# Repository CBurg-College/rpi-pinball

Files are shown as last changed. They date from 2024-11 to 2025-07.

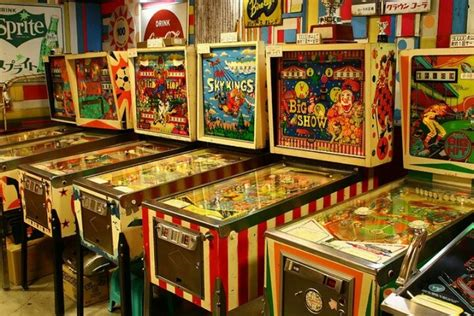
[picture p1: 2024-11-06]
installatie/testen/achtergrond.png

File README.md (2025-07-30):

## Deze repository

#### Introductie

De repositories **pxt-pinball** en **rpi-pinball** vormen een twee-eenheid.
Repository **pxt-pinball** is een uitbreiding voor **MakeCode** om de **micro:bit** te programmeren.
Het programma op de **micro:bit** werkt samen met het host-programma **Pinball** op de **Raspberry Pi**.
Repository **rpi-pinball** (deze repository dus) bevat de benodigde software en code hiervoor.
Het programma op de **micro:bit** stuurt de flipperkast dus aan via het programma **Pinball**.

#### De submappen

Submap **broncode** bevat het code-project waarmee het programma Flipperkast wordt gebouwd.
Deze is alleen interessant als het programma moet worden gewijzigd.

Submap **hardware** beschrijft de elektronische componenten in de flipperkast en hoe deze aan te sluiten.
Het bevat ook de bestanden om nieuwe flippers met de lasersnijder te snijden en deze zo nodig aan te passen.

Submap **installatie** biedt de mogelijkheid om de de **SD-kaart** van de Raspberry Pi opnieuw te installeren.
In deze map bevinden zich ook de bestanden om de flipperkast te testen.

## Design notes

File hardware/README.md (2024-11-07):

## Hardware herstellen

Een beschrijving van de flipperkast vind je in:
* **Flipperkast Werktekeningen.pdf**

Dit bestand geëxporteerd uit:
* **Flipperkast Werktekeningen.docx**

Om de elektronica van de flipperkast te herstellen, moet je kunnen solderen.
De informatie over aansluitingen en de te gebruiken onderdelen vind je in:
* **pin-aansluiting.md**
* **onderdelen.md**

Voor het vervangen van de flippers vind je de informatie in de map **flippers**.

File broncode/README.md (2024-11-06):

## Het programma Flipperkast

#### IDE Geany

Het programma **Flipperkast** is als een **Geany-project** gebouwd.
Op de Raspberry is de IDE **Geany** standaard geïnstalleerd.
Het project **Flipperkast.geany** kan daarmee worden geopend.
In de map **Flipperkast** staat de broncode.
Er is maar één code-bestand in het project aanwezig: **Flipperkast.cpp**.
Dit bestand bevat alle code van het programma.

#### C++

De code-taal van het programma **Flipperkast** is C++.
Het programma maakt gebruikt van de classes "Video" en "RgbLed" uit de code-bibliotheek **DeviceLib**.
Deze bibliotheek is als het goed is geïnstalleerd (zie bij **installatie/blanco**).
De programma-code moet samen werken met de MakeCode-uitbreiding **Flipperkast**.
De code hiervan vind je in het bestand **main.ts** van de repository **pxt-flipperkast**.

#### CLASS VIDEO

De class **Video** biedt de volgende instructies:

**Afspeelvenster**
* setTitle("Titel van het afspeelvenster");
* setSize(breedte,hoogte);
* setFullscreen();

**Frame na frame afspelen**
* start("Bestandsnaam van een video");
* play()
* rewind()
* stop()

De instructie **play** vertoont steeds het volgende frame.

**Hele video afspelen**
* play("Pad naar en bestandsnaam van een video");

**Afbeelding tonen**
* show("Pad naar en bestandsnaam van een afbeelding");

#### CLASS RGBLED

De class **RgbLed** biedt de volgende instructies:

**Instelling**
* setPin(rood,groen,blauw);
* setConnection(VCC of GND);

**Kleur**
* setColor(RED of GREEN of BLUE of YELLOW of MAGENTA of CYAN of WHITE);
* setColor(rood,groen,blauw);

**Aan/uit**
* on();
* off();

In de code mogen de instructies **setPin** en **setConnection** niet worden gewijzigd vanwege de hardware.

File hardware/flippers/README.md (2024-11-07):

## De flippers van de flipperkast

#### Het ontwerp

Het ontwerp staat in twee bestanden:
* **flipper.skp**
* **flipper.svg**

Eventuele wijzigingen kunnen in SketchUp worden gemaakt (flipper.skp),
maar de software bij de lasersnijder (**LightBurn**) heeft een svg-bestand nodig (flipper.svg).
Om in SketchUp het ontwerp als svg-bestand (flipper.svg) te exporteren is een **extension** nodig.

#### SketchUp

Het bestand **flipper.skp** is gemaakt met SketchUp Make versie 2017.
Dit is de laatste vrij installeerbare versie, omdat er nu een online versie bestaat.
Maar helaas, daarmee kun je je ontwerp niet voor de lasersnijder exporteren.
Vandaar dat we zijn aangewezen op de versie van 2017.
In de map **SVG-extension** vind je de plugin waarmee je een svg-bestand kunt exporteren:
**sketchup-svg-outline-plugin-v1.2.rbz**.
Installeer de plugin via de **Extension manager** van SketchUp (in het **Window**-menu).
**SketchUp Make 2017** kun je downloaden van https://www.filehorse.com/download-sketchup-make-64/

#### LightBurn

Het programma *LightBurn* is met licentie voor één gebruiker op de laptop van D&P geïnstalleerd.
De lasersnijder moet op de USB-ingang met het pijltje worden aangesloten.

Het bestand **flipper.svg** wordt in **LightBurn** geïmporteerd.
In deze map vind je twee bestanden waarin dat al is gebeurd:
* **flipper.lbrn2**
* **flipper20x.lbrn2**

Het bestand *flipper20x.lbrn* bevat 20 stuks flippers die uit een plaat van 55x35 cm wordt gesneden.
Gebruik een plaat triplex (4 mm dik) om de flippers uit te snijden.

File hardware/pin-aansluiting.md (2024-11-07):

#### Op de Raspberry zijn de pinnen als volgt aangesloten:

**pin  2**  ingang   **sensor poort 1**

**pin  3**  ingang   **sensor poort 2**

**pin 27**  uitgang  **rgb led 1**, kleurwaarde rood

**pin 17**  uitgang  **rgb led 1**, kleurwaarde groen

**pin 22**  uitgang  **rgb led 1**, kleurwaarde blauw

**pin 20**  uitgang  **rgb led 2**, kleurwaarde rood

**pin 16**  uitgang  **rgb led 2**, kleurwaarde groen

**pin 21**  uitgang  **rgb led 2**, kleurwaarde blauw

**pin 19**  uitgang  **rgb led 3**, kleurwaarde rood

**pin 13**  uitgang  **rgb led 3**, kleurwaarde groen

**pin 26**  uitgang  **rgb led 3**, kleurwaarde blauw

**pin  7**  ingang   **micro:bit P0**, handshaking: data valid

**pin  8**  uitgang  **micro:bit P3**, handshaking: data received

**pin  6**  uitgang  **micro:bit P1**, poort 1 bezet

**pin  5**  uitgang  **micro:bit P2**, poort 2 bezet

**pin 18**  ingang   **micro:bit P20**, media select

**pin 23**  ingang   **micro:bit P19**, media select

**pin 24**  ingang   **micro:bit P13**, led select

**pin 25**  ingang   **micro:bit P12**, led select

**pin 11**  ingang   **micro:bit P14**, led kleur: roodwaarde

**pin  9**  ingang   **micro:bit P15**, led kleur: groenwaarde

**pin 10**  ingang   **micro:bit P16**, led kleur: blauwwaarde

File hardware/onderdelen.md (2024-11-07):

#### Op de Raspberry zijn de volgende onderdelen aangesloten:

**RGB-led**:         mat, 10 mm doorsnede, common-VCC (te verkrijgen bij diverse leveranciers)

**Weerstand**:       330 Ohm (te verkrijgen bij diverse leveranciers)

**Laser poort**:     650 nm laser (rood), 5V (te verkrijgen bij TinyTronics, SKU000135)

**Sensor poort**:    sensor voor rood licht, 5V (te verkrijgen bij TinyTronics, SKU001061)

**Edge connector**:  Tru Components uitbreidingsmodule micro:bit (te verkrijgen bij Conrad, 2268132-83)

**Power converter**: TracoPower TSR 1-2433 (te verkrijgen bij Conrad, 156671-83)

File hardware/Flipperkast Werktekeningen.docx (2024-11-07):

# FLIPPERKAST Werktekening (blad 1)

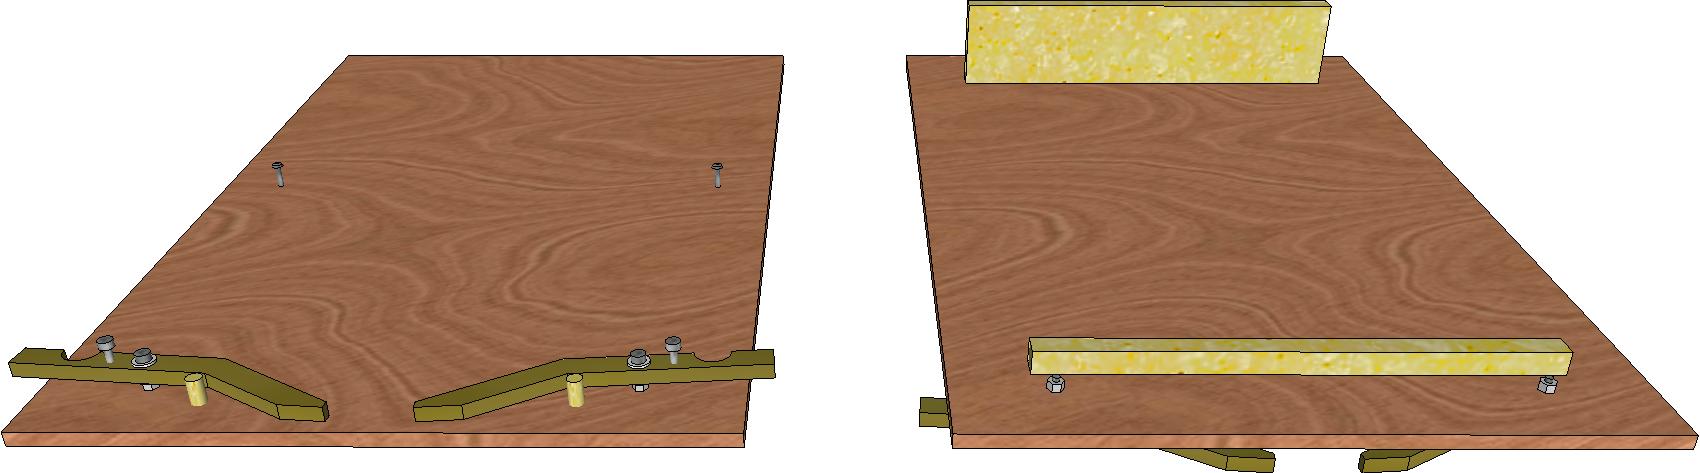
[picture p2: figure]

2

3

6

4

BOVENKANT

ONDERKANT

4

BOVENAANZICHT

ONDERAANZICHT

5

1

VOORAANZICHT

7

9

8

4

1

6

# FLIPPERKAST Werktekening (blad 2)

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
ONDERAANZICHT

# FLIPPERKAST Werktekening (blad 3)

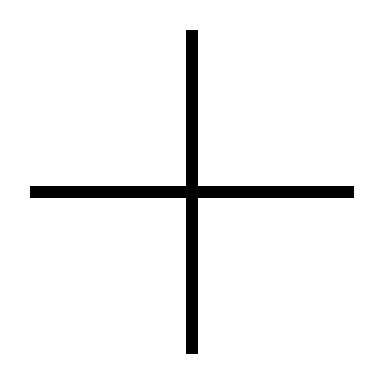
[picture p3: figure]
Toevoegen silhouet

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
BOVENAANZICHT

BOVENAANZICHT

Ø6

Ø4

Ø6

Ø4

1

# FLIPPERKAST Werktekening (blad 4)

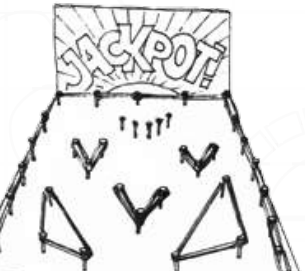
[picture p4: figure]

Ø3

ZIJAANZICHT

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
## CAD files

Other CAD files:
hardware/flippers/flippers.skp

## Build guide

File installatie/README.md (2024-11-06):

## Installatie van de Raspberry Pi

Onder de flipperkast zit een Raspberry Pi die de programma-instructies verwerkt.
De programma-instructies krijgt dit computertje van een micro:bit.

Een Raspberry doet niets zonder een SD-kaart met de benodige software.
Installeer de software volgens de onderstaande procedure.

Om te weten of de flipperkast correct functioneert, ga je naar de map **testen**.

## Procedure

#### 1. Raspberry Pi Imager

Gebruik de **Raspberry Pi Imager** tool om het standaard **Raspberry Pi OS** op een SD-kaart te schrijven.
De laatste versie van deze tool kan worden gedownload van:
[https://www.raspberrypi.com/software/

#### 2. Download de bestanden

Download de bestanden **bcm2835-1.70.tar.gz**, **DeviceLib_Raspberry.tar** en **Flipperkast**
en kopieer ze naar een USB-stick.

#### 3. Start de Raspberry

Doe de SD-kaart in de Raspberry en start hem op.
Open de **Bestandsbeheerder** van de Raspberry.
Kopieer de bestanden van de USB-stick naar **/home/pi/Download**.
Je werkt vervolgens vanuit deze map.

#### 4. Installeer de BCM2835 bibliotheek

Het hart van de Raspberry (t/m versie 4) is de bcm2835-chip.
Om het programma **Flipperkast** daarmee te laten samenwerken is een code-bibliotheek nodig.
Dubbel-klik op het bestand **bcm2835-1.70.tar.gz** om de code-bibliotheek te installeren.

#### 5. Installeer de DeviceLib bibliotheek

Het programma **Flipperkast** maakt gebruik van de **DeviceLib**-bibliotheek om video's af te spelen.
Dubbel-klik op het bestand **DeviceLib_Raspberry.tar** om de bibliotheek uit te pakken.
Open vervolgens de map **DeviceLib_Raspberry** en dubbel-klik op het bestand **Install.sh**.
Daarmee is **DeviceLib** geïnstalleerd.

#### 6. Het programma Flipperkast

Kopieer het programma **Flipperkast** naar het bureaublad om er gemakkelijker mee te kunnen werken.

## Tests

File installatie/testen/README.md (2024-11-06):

## De flipperkast testen

#### Bestanden kopiëren

De bestanden in deze map zijn bedoeld om de flipperkast mee te testen.
Schrijf deze bestanden in de **root** van een USB-stick met de volumenaam **BRG2**.

#### Micro:bit programma maken

Start **MakeCode** en sluit een **micro:bit** aan.
Importeer het programma **Flipperkast_test.hex** van de USB-stick.
Klik op het vlak **Downloaden** om het programma naar de **micro-bit** te schrijven.

#### Programma testen

Start de raspberry onder de flipperkast op.
Het programma **Flipperkast** vind je op het bureaublad.
(Zo niet, kijk dan eerst in de map **installatie/blanco**.)
Dubbel-klik op het programma en kies de optie **Uitvoeren in terminal**. 

Plaats de USB-stick in een USB-ingang van de Raspberry onder de flipperkast.
Plaats de **micro:bit** in de edge-connector.
Als het goed is werkt het programma nu.
* Led 3 moet voortdurend van kleur veranderen
* Sluit met je vinger poortje 1: Led 1 wordt rood en **video1.mp4** wordt getoond.
* Sluit met je vinger poortje 2: Led 2 wordt rood en **video2.mp4** wordt getoond.
* Na het afspelen van een video wordt **achtergrond.png** getoond.

#### Controleren in de terminal

Je kunt de werking van het programma **Flipperkast** als volgt controleren.
Terwijl het programma draait, klik je op het tabblad **uxterm** in de werkbalk bovenin het scherm.
De terminal verschijnt op het scherm.
Bij iedere test-actie (hierboven beschreven) meldt de terminal wat het programma precies doet.
Als het goed is, zie dat terug op de flipperkast.
(Zo niet, dan is de hardware defect. Kijk dan in de map **hardware**)

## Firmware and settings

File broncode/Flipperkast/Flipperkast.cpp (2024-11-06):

#include <video.h>
#include <rgbled.h>

/* HARDWARE				RPI
 * ------------------------
 * GATE1				2
 * GATE2				3
 * 
 * LED1 RED				27
 * LED1	GREEN			17
 * LED1 BLUE			22
 * 
 * LED2 RED				20
 * LED2 GREEN			16
 * LED2 BLUE			21
 * 
 * LED3	RED				19
 * LED3 GREEN			13
 * LED3 BLUE			26
*/

#define PIN_GATE1_IN	2
#define PIN_GATE2_IN	3
#define PIN_L1_RED		27
#define PIN_L1_GREEN	17
#define PIN_L1_BLUE		22
#define PIN_L2_RED		20
#define PIN_L2_GREEN	16
#define PIN_L2_BLUE		21
#define PIN_L3_RED		19
#define PIN_L3_GREEN	13
#define PIN_L3_BLUE		26

/* COMMUNICATION		MBIT <>	RPI
 * -------------		-----------
 * GATE1 CLOSED			P1	 <	6
 * GATE2 CLOSED			P2	 <	5
 * 
 * DATA VALID			P0	 >	7
 * DATA RECEIVED		P3	 <	8
 * 
 * DATA:
 * -----
 * MEDIA SELECT			P20	 >	18
 * MEDIA SELECT			P19	 >	23
 * LED SELECT			P13	 >	24
 * LED SELECT			P12	 >	25
 * LED COLOR RED		P14  >	11
 * LED COLOR GREEN		P15  >	9
 * LED COLOR BLUE		P16  >	10
*/

#define PIN_GATE1_OUT	6
#define PIN_GATE2_OUT	5

#define PIN_DVALID		7
#define PIN_DRECEIVED	8

#define PIN_MEDSEL_A	18
#define PIN_MEDSEL_B 	23
#define PIN_LEDSEL_A	24
#define PIN_LEDSEL_B	25
#define PIN_RED			11
#define PIN_GREEN		9
#define PIN_BLUE		10

// -------------------

Video 	vid;
RgbLed	led1;
RgbLed	led2;
RgbLed	led3;

int ledsel = 0;
int medsel = 0;
int gt1 = 1;
int gt2 = 1;


int color[] = { 0, RED, GREEN, YELLOW, BLUE, MAGENTA, CYAN, WHITE };
EString cs[] = { "uit", "rood", "groen", "geel", "blauw", "paars", "l.blauw", "wit" };

// -------------------

void setup()
{
	// HARDWARE

	led1.setPin( PIN_L1_RED, PIN_L1_GREEN, PIN_L1_BLUE);
	led2.setPin( PIN_L2_RED, PIN_L2_GREEN, PIN_L2_BLUE);
	led3.setPin( PIN_L3_RED, PIN_L3_GREEN, PIN_L3_BLUE);
	led1.setConnection( VCC);
	led2.setConnection( VCC);
	led3.setConnection( VCC);

	vid.setTitle( "Flipperkast");
	vid.setAcceleration( 4);
	vid.setFullScreen();

	// MICRO:BIT

	pinMode( PIN_GATE1_OUT, OUTPUT);
	pinMode( PIN_GATE2_OUT, OUTPUT);
	digitalWrite( PIN_GATE1_OUT, LOW);
	digitalWrite( PIN_GATE2_OUT, LOW);

	pinMode( PIN_DVALID, INPUT);
	pinMode( PIN_DRECEIVED, OUTPUT);
	digitalWrite( PIN_DRECEIVED, LOW);

	pinMode( PIN_MEDSEL_A, INPUT);
	pinMode( PIN_MEDSEL_B, INPUT);

	pinMode( PIN_LEDSEL_A, INPUT);
	pinMode( PIN_LEDSEL_B, INPUT);
	pinMode( PIN_RED, INPUT);
	pinMode( PIN_GREEN, INPUT);
	pinMode( PIN_BLUE, INPUT);

	// START

	led1.off();
	led2.off();
	led3.off();
	printf( "GESTART\n\n");
}

void loop()
{
	if ( digitalRead( PIN_GATE1_IN) != gt1 ) {
		digitalWrite( PIN_GATE1_OUT, gt1);
		gt1 = (gt1 ? 0 : 1);
		if ( !gt1 )
			printf( "Door poortje 1\n");
	}
	if ( digitalRead( PIN_GATE2_IN) != gt2 ) {
		digitalWrite( PIN_GATE2_OUT, gt2);
		gt2 = (gt2 ? 0 : 1);
		if ( !gt2 )
			printf( "Door poortje 2\n");
	}

	if ( !digitalRead( PIN_DVALID) ) return;

	ledsel = (digitalRead( PIN_LEDSEL_A) * 2) + digitalRead( PIN_LEDSEL_B);
	medsel = (digitalRead( PIN_MEDSEL_A) * 2) + digitalRead( PIN_MEDSEL_B);

	if ( ledsel ) {
		RgbLed* led;
		switch ( ledsel ) {
			case 1 : led = &led1; break;
			case 2 : led = &led2; break;
			case 3 : led = &led3; break;
		}
		int clr = digitalRead( PIN_RED) + digitalRead( PIN_GREEN) * 2 + digitalRead( PIN_BLUE) * 4;
		if ( clr ) {
			led->setColor( color[clr]);
			led->on();
			printf( "Led %d op %s\n", ledsel, cs[clr].c_str());
		}
		else {
			led->off();
			printf( "Led %d uit\n", ledsel);
		}
	}
	else
	if ( medsel ) {
		switch ( medsel ) {
			case 1 :	printf( "Start 'video1.mp4' van usb 'BRG2'\n");
						vid.play( "/media/pi/BRG2/video1.mp4");
						break;
			case 2 :	printf( "Start 'video2.mp4' van usb 'BRG2'\n");
						vid.play( "/media/pi/BRG2/video2.mp4");
						break;
			default:	vid.show( "/media/pi/BRG2/achtergrond.png");
						printf( "Toont 'achtergrond.png' van usb 'BRG2'\n");
		}
	}
	else
		return; // invalid, should never happen

	digitalWrite( PIN_DRECEIVED, HIGH);
	while ( digitalRead( PIN_DVALID) );
	digitalWrite( PIN_DRECEIVED, LOW);
}
